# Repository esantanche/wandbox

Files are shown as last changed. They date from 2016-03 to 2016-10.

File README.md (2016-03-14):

Wandbox, Raspberry Pi 3 Laptop 
===================

This is a project for a laptop based on Raspberry Pi 3.
The components are contained in a plywood box.
The monitor will be mounted on top of the box.

Where to begin
--------------
Schematics_Components.odg shows how the laptop's components are placed and how power flows from the external power 
supply to the battery charger, to the batteries, to the switch and, from there to all other components.

The documents whose name begins with "Components" describe single components, where I plan to buy them from and
give technical details.

The documents whose name begins with "Tools" describe tools I'll use for the project.

The documents whose name begins with "Detail" show solutions used to solve specific problems.

Disclaimer
====================
I'm not endorsing any product here. I'm just saying which products I'm using.
You may find better products or completely different solutions.
Do your own research.

Do your own research about fire risks or any other risk. Carefully study how to minimise these risks.
I don't assume any responsibility if your home blows up and you with it. ;-)

Take care when using tools like saws or cutters, they are dangerous!

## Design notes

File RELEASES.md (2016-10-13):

Releases history
===================

1.0
===================
Made 3D and 2D schemas of box
Had the box's parts laser-cut
Built the box
Tested everything again
Added heating sinks
Completed many documents

0.3
===================
Tested these components: 12V voltage regulator, 5V voltage regulator, power switch. See results in PhotoGallery
Performed many experiments with batteries. Results in PhotoGallery as well.
Tested short HDMI cable
Tested keyboard
Updated many documents 
Started to design the plywood box. See document 010_what_the_box_will_be_like.odt in PhotoGallery

0.2
===================
I got the monitor! The delivery has been incredibly faster than expected.
I made many changes.
I'm using a different switch to power on the laptop. See ComponentsPowerOnSwitch.odt.
I made some photos with explanations. See PhotoGallery folder.

0.1
===================
Initial release

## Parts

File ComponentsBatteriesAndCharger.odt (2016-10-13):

Components:

Batteries and charger

# Batteries

These are 4400 mAh batteries for a total voltage of 11.1V (3.7 x 3)

http://www.ebay.com/itm/SAMSUNG-Rechargeable-Li-ion-Battery-18650-22F-11-1V-4400MAH-3S2P-6pcs-cell-/220999843383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

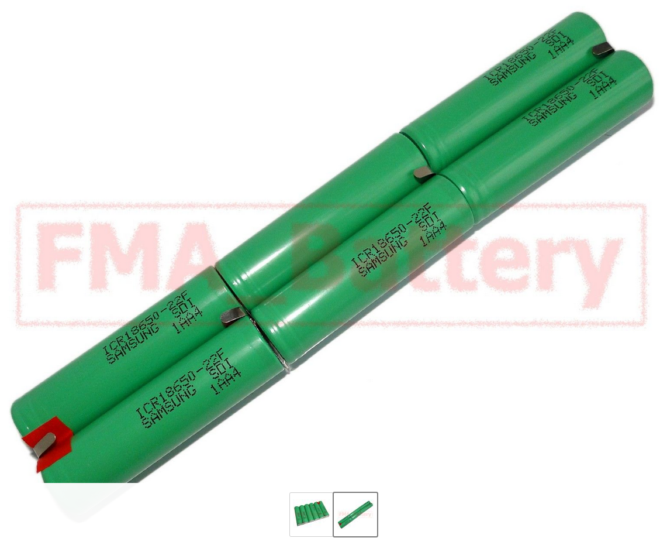
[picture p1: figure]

# Battery charger

It charges batteries and balances battery charge so that there is no risk that a battery ends up overcharged with the other batteries undercharged. It protects the batteries from overcharge, overcurrent and short circuit.

http://www.ebay.com/itm/Balance-BMS-Protected-Module-PCM-3S-4A-11-1V-Li-ion-Li-Po-Battery-3S4W007-/221791091395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

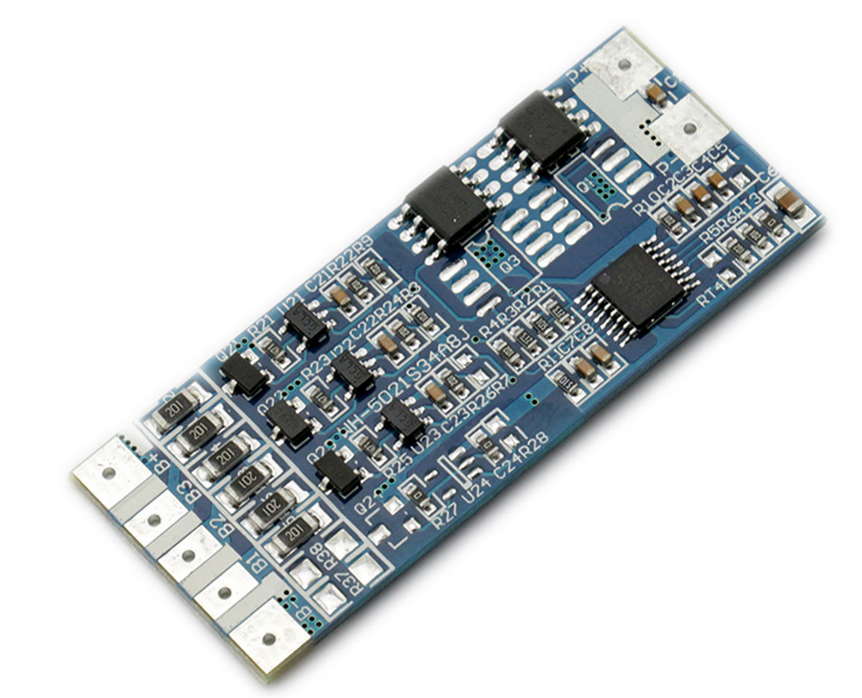
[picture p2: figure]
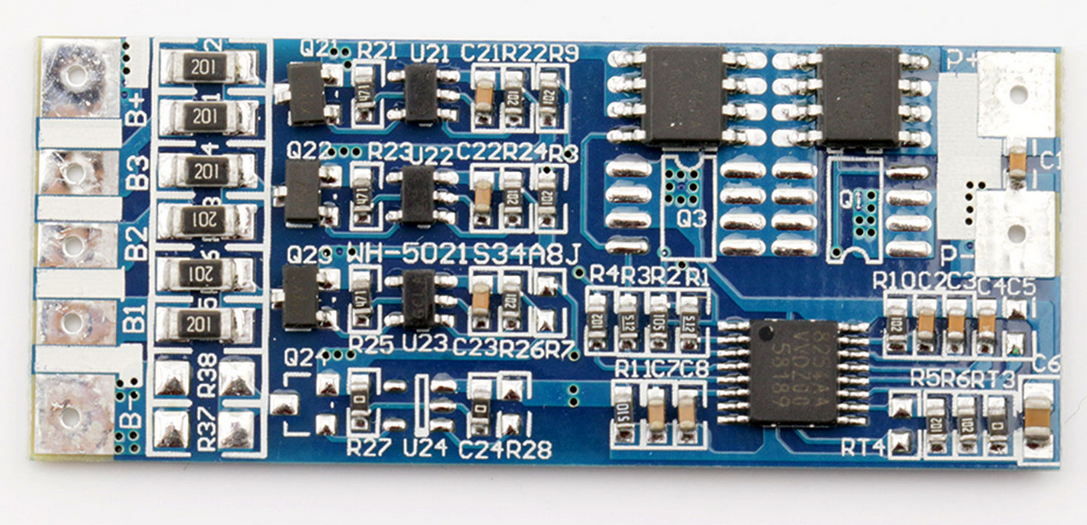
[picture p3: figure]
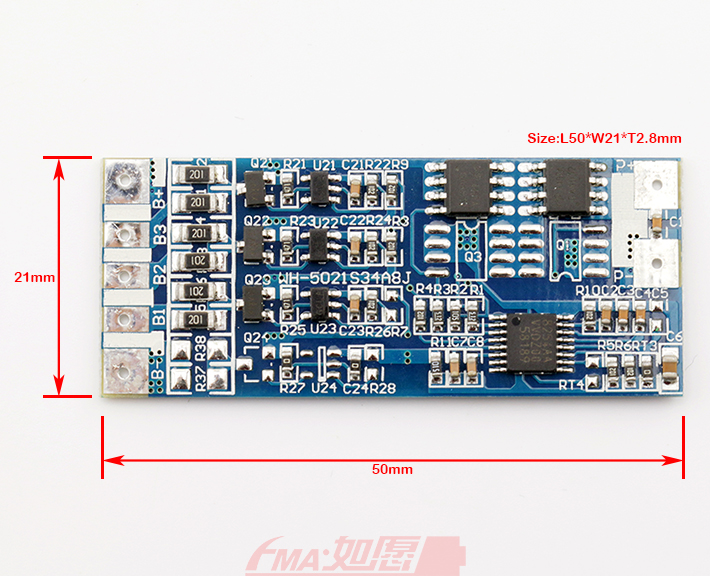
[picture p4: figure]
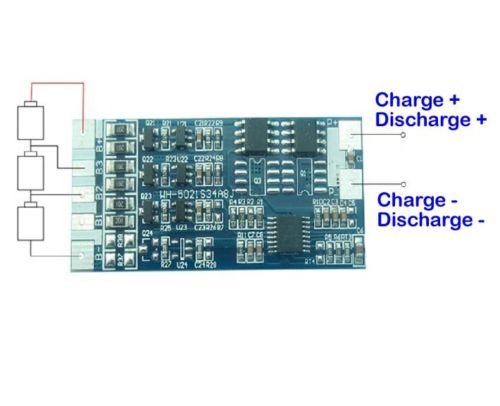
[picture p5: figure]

No | Test Item | | Criterion
1 | Voltage | Charging voltage | DC:13.5-15V CC/CV
| | Balance voltage for single cell | 4.2V
2 | Current | Balance current for single cell | 42mA
| | Current consumption | ≤15μA
| | Maximal continuous charging current | N/A
| | Maximal continuous Discharging current | 4.5A
3 | Over charge Protection | Over charge detection voltage | 4.350±0.025V
| | Over charge detection delay time | 1S
| | Over charge release voltage | 4.15±0.05V
4 | Over discharge protection | Over discharge detection voltage | 2.7±0.08V
| | Over discharge detection delay time | 100mS
| | Over discharge release voltage | 3.0±0.1V
5 | Over current protection | Over current detection voltage | 200±25mV
| | Over current detection current | 17±3A
| | Detection delay time | 10ms
| | Release condition | Cut load
6 | Short Circuit protection | Detection condition | Exterior short circuit
| | Detection delay time | ≤600us
| | Release condition | Cut load
7 | Resistance | Protection circuitry（MOSFET） | ≤15mΩ
8 | Temperature | Operating Temperature Range | -40～+85℃
| | Storage Temperature Range | -40～+125℃

# Min and max voltage of batteries

When fully charged these batteries have a 4.2V voltage. Which means 12.6V total voltage. The monitor should be able to tolerate this voltage even with no voltage regulator.

When discharging batteries go as low as 3V. This is a real minimum. So we have at least 9V in total.

https://learn.adafruit.com/li-ion-and-lipoly-batteries/voltages

# Additional charging and protection circuitry

Maybe I have to buy another one

http://www.ebay.co.uk/itm/111526325783?_trksid=p2055119.m1438.l2649&ssPageName=STRK%3AMEBIDX%3AIT

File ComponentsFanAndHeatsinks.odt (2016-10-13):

Fan and heatsinks

# Heatsinks

I got these heatsinks:

https://www.modmypi.com/raspberry-pi/accessories/heat-sinks-and-cooling/raspberry-pi-heat-sink-kit-red/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

As shown in the document 014_Overtemperature_problem.odt heatsinks don't lower cpu's temperature so much. But anyway, they are a start.

# Fans

I could get a fan like this one:

http://www.ebay.co.uk/itm/400895288849

Or maybe this one:

http://www.dx.com/p/active-cooling-mini-fan-for-raspberry-pi-3-model-b-2b-b-black-430935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

Or this one:

http://uk.rs-online.com/web/p/axial-fans/7588194/

For now I'll leave it as it is because, anyway, I'm not going to use the laptop for intensive tasks. The temperature should get very high.

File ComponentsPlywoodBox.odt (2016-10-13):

Components:

Plywood box

# 6.4 mm and 3.2 mm plywood

Initially I wanted to use 6.4 mm and 3.2 mm plywood.

This is the product I wanted to use:

http://modelshop.co.uk/Shop/Raw-Materials/Wood-Sheet/Item/Plywood-304-304mm/ITM3996

I got a single 6.4 mm sheet just to mount components on and test them.

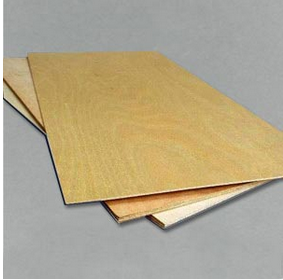
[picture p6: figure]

The problem is that this plywood is not suitable for laser cutting.

# Laser quality plywood

So I used laser quality plywood.

This is the product:

http://modelshop.co.uk/Shop/Raw-Materials/Wood-Sheet/Plywood/Item/Plywood-800-450mm/ITM4013

# Drawings

Drawing filename | Type of file | Description
2d-drawing-to-cut-box-parts-4-mm-plywood-sheet.dxf | LibreCAD | This is the drawing sent to Modelshop.co.uk for them to cut the parts I needed to build the box
2d-drawing-to-cut-box-parts-4-mm-plywood-sheet (red lines).dxf | LibreCAD | This is the same with red lines for another laser cut service I didn't actually use
wandbox-wings3d.wings | Wings3D | 3D model of the box with 6.4 mm and 3.2 mm plywood. I didn't build this box eventually
wandbox-wings3d-4mm-plywood.wings | Wings3D | 3D model of the box I actually built

# Other laser cutting services

http://www.cutlasercut.com

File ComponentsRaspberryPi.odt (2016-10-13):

Components:

Raspberry Pi

I got a Raspberry Pi 3:

https://www.newit.co.uk/shop/all-raspberry-pi/raspberry_pi_3/raspberry_pi3

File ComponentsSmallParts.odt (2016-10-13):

Components:

Small parts

# Screws

I need these sizes:

- length 5 mm (this are used for components that are directly screwed to plywood)
- length 8 mm (to mount the raspberry pi; these have to be longer because the raspberry pi needs space underneath, it can't be mounted directly to plywood)

I got these screws from a local modelling shop.

I got 9.5 mm and 6.4 mm ones.

I got as well 8 mm screws needed for 4mm plywood.

I got them here: http://www.ebay.co.uk/itm/272176439778?_trksid=p2057872.m2749.l2649&ssPageName=STRK%3AMEBIDX%3AIT

# DC Power Plug

http://www.hobbytronics.co.uk/cables-connectors/misc-connectors/dc-power-plug

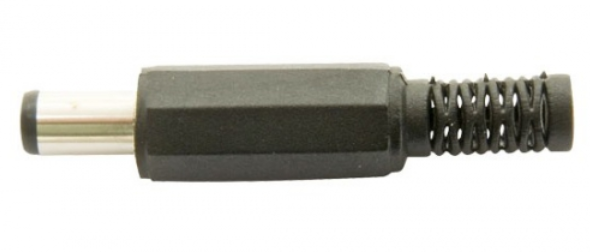
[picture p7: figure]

This is to power the monitor control board.

# Spacers

I'm going to use these spacers to make space between Raspberry Pi and the plywood box. I'll use them for all other boards.

http://www.hobbytronics.co.uk/hardware/spacers-washers/nylon-round-spacer-4mm

# Washers

I used washers for the monitor control board.

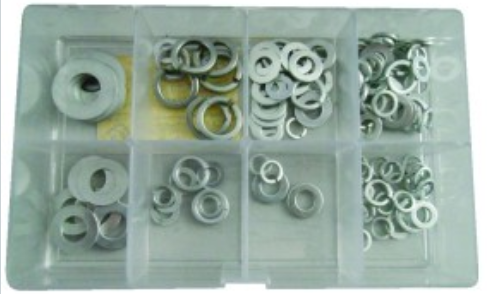
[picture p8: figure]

These are metallic washers, but for the monitor control board it's fine.

I had to use them because the monitor control board has quite large mounting holes and my screws are small.

I got these metallic washers from Maplin.

I got more washers, smaller ones, here: http://www.modelfixings.co.uk/washers.htm#Flat washers

These are M2 washers I needed because my screws are small and the washers I already had were too big.

Other examples

- http://www.hobbytronics.co.uk/hardware/spacers-washers/nylon-washer-m25
- http://uk.rs-online.com/web/p/products/0528154/
- http://www.ebay.co.uk/itm/M3-M4-M5-M6-M8-M10-M20-Nylon-Washer-Plastic-Washer-Nylon-Insulation-Soft-Gasket-/171983814762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 (http://www.ebay.co.uk/itm/M3-M4-M5-M6-M8-M10-M20-Nylon-Washer-Plastic-Washer-Nylon-Insulation-Soft-Gasket-/171983814762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)

# Cable

It has to be 0.8 or 1 mm of diameter.

I got a 0.6mm one that should be OK anyway because it's rated 4A. I got it from Maplin.

It's a rigid cable that has a single core.

# Jumpers

Jumpers 1x2 to power Raspberry Pi via GPIO and to use to connect boards.

http://www.hobbytronics.co.uk/crimp-conn-housing-2


Pins to be inserted in the jumpers above:

http://www.hobbytronics.co.uk/crimp-conn-pins


Other products:

- http://uk.rs-online.com/web/p/products/7916450/#
- http://www.maplin.co.uk/p/jumper-wires-raspberry-pi-40-way-ribbon-male-female-tear-off-strips-n75de
- http://www.hobbytronics.co.uk/cables-connectors/crimp-connectors/crimp-conn-housing-22
- http://www.hobbytronics.co.uk/cables-connectors/jumper-wires-mf-6in

Other ideas:

How to make your own jumpers: http://www.basicxandrobotics.com/tutorials/jumpers/

How to make custom connectors: https://www.youtube.com/watch?v=M84VcMeAzzw

# Cable tie bases

Now I'm not using these cable ties.

Maplin has them.

Useful to tie small cables.

This is just an example to show what I'm talking about:

http://www.ebay.co.uk/itm/SELF-ADHESIVE-CABLE-TIE-BASE-MOUNTS-STICKY-BACKED-BLACK-WHITE-19mm-25mm-28mm-/181011054666

# Crimp terminals

I used crimps only to connect the batteries. To distribute power I used terminals.

I used crimps like these:


I got some other crimp terminals with the crimper, but I haven't used them.

Eventually I used a lot of terminals to distribute power.


Terminals

# Fasteners

I'm not going to use these.

These cable ties are used to fasten the batteries:

http://www.cabletiesonline.co.uk/cable-ties-screw-mount/screw-mount-cable-ties-110-x-2-5mm/prod_961.html

# Crocodile clips

I got a couple of crocodile clips from my old stuff.

http://www.hobbytronics.co.uk/crocodile-clips?keyword=clip

Useful information:

How to attach an alligator clip to a wire

https://www.youtube.com/watch?v=DrEzG1gwYOg

# Plastic profiles

I used plastic profiles for the box. They allow me to place screws not too near the borders. If I put a screw near a border, it damages the wood.


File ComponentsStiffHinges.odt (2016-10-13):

Components:

Stiff hinges

These hinges make it possible to adjust the incline of the monitor.

They are stiff, which means that they stay put at the angle you give them.

This is the link to the product: http://uk.rs-online.com/web/p/hinges/7729638/


Hinges at work!


These hinges are adjustable. If they don't stay put at the angle you give them, you can tight the screws and they get more stiff.

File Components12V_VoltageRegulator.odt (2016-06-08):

Components:

12V Voltage regulator

This voltage regulator is for the monitor.

I'm using this one:

http://www.hobbytronics.co.uk/s18v20f12-12v-regulator


### How I used it

I just soldered the blue terminals you see above to the pins GND, VIN and VOUT. VIN has to be connected to the positive pole of the batteries charger or of the PSU. VOUT goes to the monitor. The GND pin on the input side has to be connected to the negative pole of the batteries charger or of the PSU. The GND pin on the output side goes to the monitor. No need to use the ENABLE pin.

### 12V Step-Up/Step-Down Voltage Regulator S18V20F12

This powerful step-up/step-down regulator efficiently produces a fixed 12 V output from input voltages between 3 V and 30 V while allowing a typical output current of up to 2 A when the input voltage is close to the output voltage and offering typical efficiencies of 80% to 90%. Its ability to convert both higher and lower input voltages makes it useful for applications where the power supply voltage can vary greatly, as with batteries that start above but discharge below the regulated voltage.

The flexibility in input voltage offered by these regulators is especially well-suited for battery-powered applications in which the battery voltage begins above the desired output voltage and drops below the target as the battery discharges.

The no-load quiescent will typically be between 1mA and 5mA for all possible combinations of input and output voltages (e.g. the quiescent current is approximately 4mA with 3V in, 1.5mA with 12V in, and 1mA with 30V in). The ENABLE pin can be used to put the board in a low-power state that reduces the quiescent current to between 10 and 20µA per volt on VIN (e.g. approximately 30µA with 3V in and 500µA with 30V in).

This regulator has built-in reverse-voltage protection, over-current protection, thermal shutdown (which typically activates at 165°C), and an under-voltage lockout that causes the regulator to turn off when the input voltage is below 2.5 V (typical).

Features

- Input voltage: 2.9V to 32V (32 V is the absolute maximum operating voltage; the recommended maximum operating voltage is 30 V, which is the limit of the reverse voltage protection.)
- Fixed 12V output with 4% accuracy
- Typical maximum continuous output current: 2A (when input voltage is close to the output voltage; the Typical Efficiency and Output Current section below shows how the achievable continuous output current depends on input and output voltages)
- Integrated reverse-voltage protection (up to 30V), over-current protection, over-temperature shutoff, and under-voltage lockout
- Typical efficiency of 80% to 90%, depending on input voltage, output voltage, and load
- Four mounting holes for #2 or M2 screws.
- Compact size: 1.7″ × 0.825″ × 0.38″ (43 × 21 × 10 mm)
- Smaller holes for 0.1″ header pins and larger holes for terminal blocks offer several options for connecting to the board.

Connections

This step-up/step-down regulator has four connections: input voltage (VIN), ground (GND), and output voltage (VOUT), and ENABLE.

The input voltage, VIN, should be between 2.9 V and 32 V. Lower input voltages can cause the regulator to shut down or behave erratically; higher input voltages can destroy the regulator, so you should ensure that noise on the input is not excessive. 32 V should be treated as the absolute maximum input voltage. Our recommended maximum operating voltage is 30 V, which is the limit of the reverse voltage protection.

The regulator is enabled by default: a 100 kΩ pull-up resistor on the board connects the ENABLE pin to reverse-protected VIN. The ENABLE pin can be driven low (under 0.7 V) to put the board into a low-power state. The quiescent current draw in this sleep mode is dominated by the current in the pull-up resistor from ENABLE to VIN and by the reverse-voltage protection circuit, which will draw between 10 µA and 20 µA per volt on VIN when ENABLE is held low (e.g. approximately 30 µA with 3 V in and 500 µA with 30 V in). If you do not need this feature, you should leave the ENABLE pin disconnected. Note that the SEPIC topology has an inherent capacitor from input to output; therefore, the output is not completely disconnected from the input even when the regulator is shut down.

Output Current

The maximum achievable output current of the board varies with the input voltage but also depends on other factors, including the ambient temperature, air flow, and heat sinking. The graphs below show output currents at which this voltage regulator’s over-temperature protection typically kicks in after a few seconds. These currents represent the limit of the regulator’s capability and cannot be sustained for long periods, so the continuous currents that the regulator can provide are typically several hundred milliamps lower.

## Other ideas

- https://www.coolcomponents.co.uk/adjustable-4-12v-step-up-step-down-voltage-regulator-s18v20alv.html

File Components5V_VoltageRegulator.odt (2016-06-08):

Components:

5V Voltage regulator

This voltage regulator is to power the Raspberry Pi.

This is the 5V voltage regulator I got:

http://www.hobbytronics.co.uk/electronic-components/voltage-regulators/voltage-regulator-5v/d24v22f5-5v-step-down-regulator


### How I used it

I needed just to connect GND to the negative pole of the batteries charger. The latter, when it's not under charge, allows the batteries power to flow through it to power anything you connect to it.

The pin VIN has to be connected to the batteries charger as well.

The pin VOUT goes to power the Raspberry Pi. The latter will take GND from the battery charger.

There is no need to use the pins PG and EN.

### 5V 2.5A Step-Down Voltage Regulator D24V22F5

This small synchronous switching step-down (or buck) regulator takes an input voltage of up to 36 V and efficiently reduces it to 5 V. The board measures only 0.7″ × 0.7″ yet delivers a typical continuous output current of up to 2.5 A and features reverse voltage protection. Typical efficiencies of 85% to 95% make this regulator well suited for powering moderate loads like sensors or small motors. An optional shutdown pin enables a low-power state with a current draw of around 20 μA to 350 μA, depending on the input voltage, and a power-good output indicates when the regulator cannot adequately maintain the output voltage.

These regulators have a typical quiescent (no load) current draw of around 1 mA, and an enable pin can be used to put the boards in a low-power state that reduces the quiescent current to approximately 5 µA to 10 µA per volt on VIN.

The modules have built-in reverse-voltage protection, short-circuit protection, a thermal shutdown feature that helps prevent damage from overheating, and a soft-start feature that reduces inrush current.

Features

- Input voltage: 6 V to 38 V (see below for more details on the regulator’s dropout voltage, which affects the low end of the operating range)
- Fixed 5 V output (with 4% accuracy)
- Typical maximum continuous output current: > 2.5 A
- Integrated reverse-voltage protection, over-current protection, over-temperature shutoff, soft-start, and under-voltage lockout
- Typical efficiency of 85% to 95%, depending on input voltage and load; the switching frequency automatically changes at light loads to maintain high efficiencies
- 1 mA typical no-load quiescent current; this can be reduced to approximately 5 µA to 10 µA per volt on VIN by disabling the board
- “Power good” output indicates when the regulator cannot adequately maintain the output voltage
- Compact size: 0.7″ × 0.7″ × 0.31″ (17.8 mm × 17.8 mm × 8 mm)
- Two 0.086″ mounting holes for #2 or M2 screws

These buck regulators have five main connection points for five different electrical nodes: power good (PG), enable (EN), input voltage (VIN), ground (GND), and output voltage (VOUT). The board also features a second ground connection point off the main row of connections that might be convenient for applications where you are soldering wires directly to the board rather than using it in a breadboard.

The input voltage, VIN, powers the regulator and can be supplied with voltages up to 38 V. The effective lower limit of VIN is VOUT plus the regulator’s dropout voltage, which varies approximately linearly with the load (see below for a graph of dropout voltages as a function of the load).

The regulator is enabled by default: a 270 kΩ pull-up resistor on the board connects the EN pin to reverse-protected VIN. The EN pin can be driven low (under 1 V) to put the board into a low-power state. The quiescent current draw in this sleep mode is dominated by the current in the pull-up resistor from EN to VIN and by the reverse-voltage protection circuit, which altogether will draw between 5 µA and 10 µA per volt on VIN when EN is held low. If you do not need this feature, you should leave the EN pin disconnected.

The “power good” indicator, PG, is an open-drain output that goes low when the regulator’s output voltage falls below around 85% of the nominal voltage and becomes high-impedance when the output voltage rises above around 90%. An external pull-up resistor is required to use this pin.

## Other ideas

- http://www.dx.com/p/hobbywing-5v-6v-3a-switch-mode-ultimate-bec-ubec-15149#.VuCzLeinxJ8
- http://www.dx.com/p/8s-5a-switch-mode-ultimate-bec-ubec-45214#.VuFjIjp6elN
- http://uk.rs-online.com/web/p/products/0633026/

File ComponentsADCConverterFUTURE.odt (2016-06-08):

FIXME I'll add this in the future

(https://shop.pimoroni.com/products/adafruit-ads1115-16-bit-adc-4-channel-with-programmable-gain-amplifier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)

https://shop.pimoroni.com/products/adafruit-ads1115-16-bit-adc-4-channel-with-programmable-gain-amplifier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

FIXME future addition

ADC converter to measure batteries voltage

You have to enable I2C interface in raspberry pi configuration

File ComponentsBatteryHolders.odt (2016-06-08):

Components:

Battery holders

I didn't use battery holders.


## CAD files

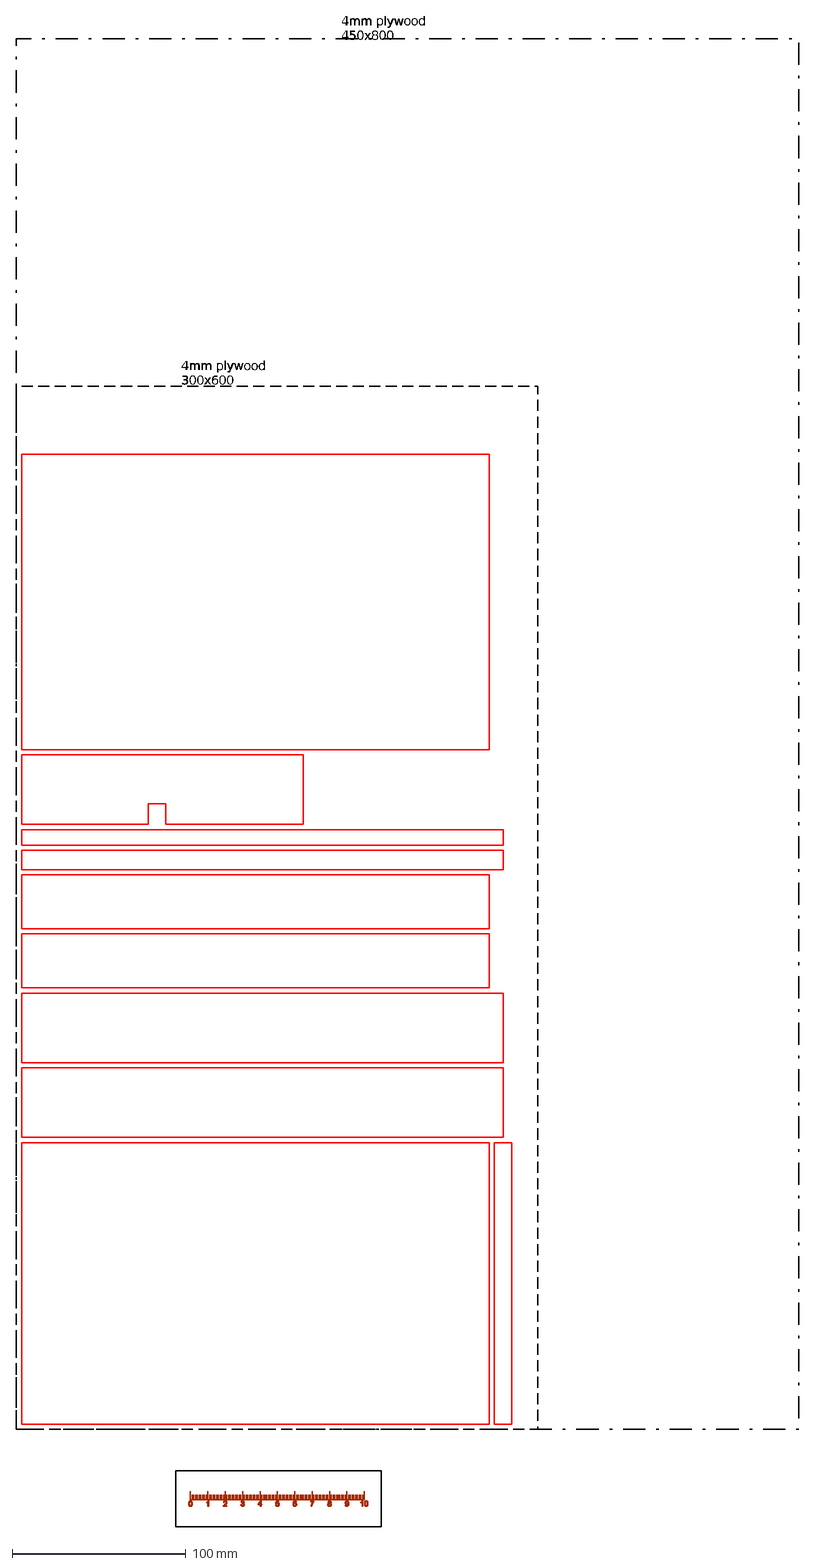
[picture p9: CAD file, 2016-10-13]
2d-drawing-to-cut-box-parts-4-mm-plywood-sheet (red lines).dxf
4mm plywood 300x600
4mm plywood 450x800

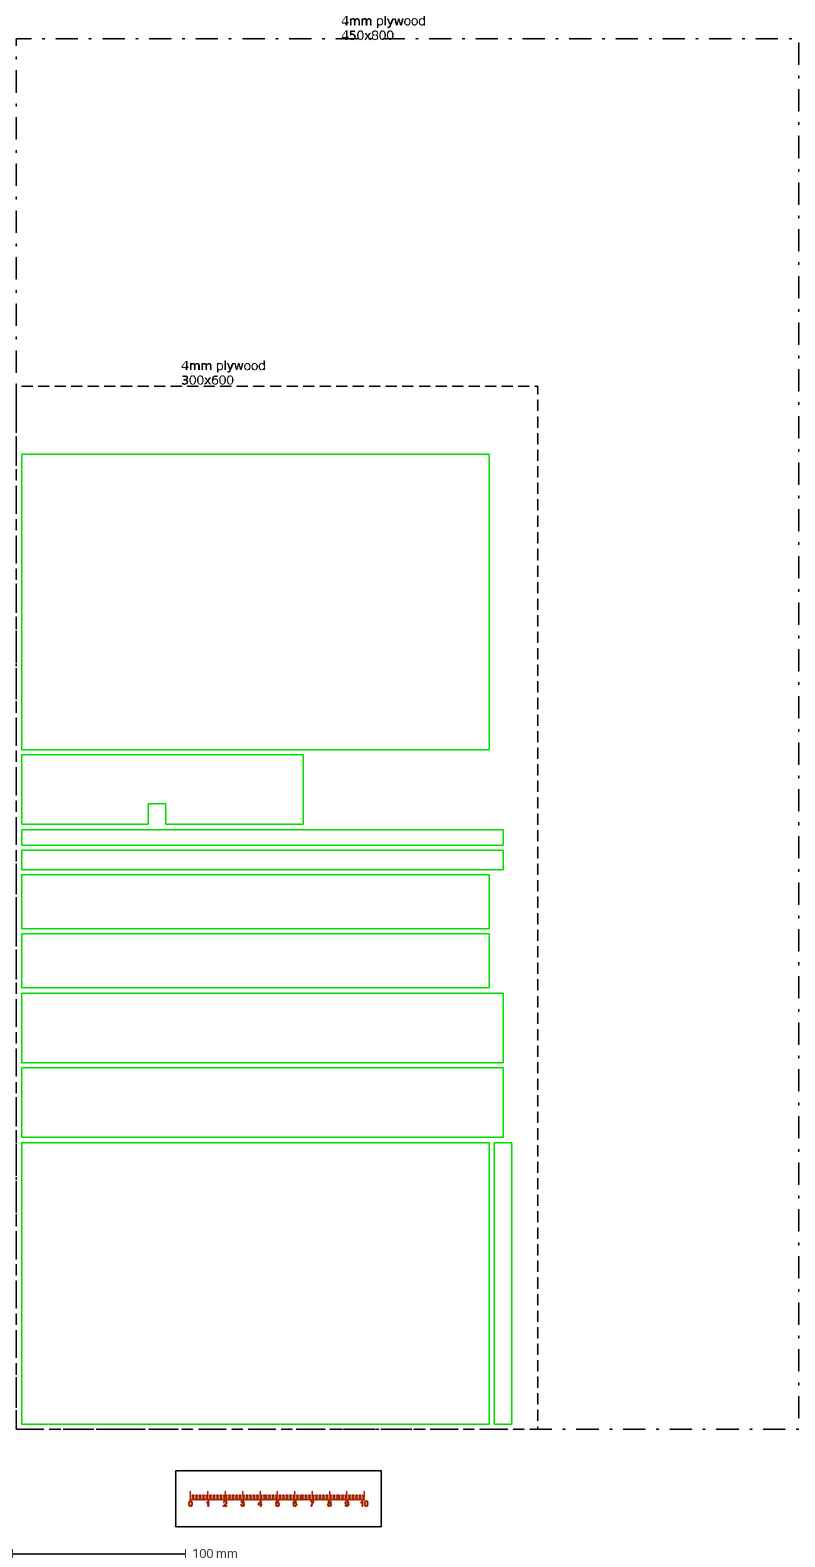
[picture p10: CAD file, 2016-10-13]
2d-drawing-to-cut-box-parts-4-mm-plywood-sheet.dxf
4mm plywood 300x600
4mm plywood 450x800

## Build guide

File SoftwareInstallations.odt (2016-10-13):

Wandbox, software installations

# Installation of NOOBS

Followed standard procedure from https://www.raspberrypi.org/help/noobs-setup/

Just make sure that the SD card is formatted FAT32 and not extended FAT.

# Connect to wifi

Click on the network icon on the right of the top panel.

You get a list of wifi networks. You may have to wait a little for the scan to complete.

Select your wifi network.

Give your password.

# Update and upgrade

To update Raspbian to latest version, give these commands:

sudo apt-get update

sudo apt-get dist-upgrade

reboot.

# Set locale and keyboard

Go to Menu→Preferences→Raspberry Pi configuration

Go to localisation tab

Set your locale, timezone and keyboard

# Firefox

Go to Menu→Preferences→Add/Remove Software

Search for Firefox

Select “Mozilla Firefox web browser”

Click Apply

The password is raspberry if you didn't change it.

# Chromium

With this procedure you install Chromium:

wget -qO - http://bintray.com/user/downloadSubjectPublicKey?username=bintray | sudo apt-key add -
echo "deb http://dl.bintray.com/kusti8/chromium-rpi jessie main" | sudo tee -a /etc/apt/sources.list
sudo apt-get update
sudo apt-get install chromium-browser rpi-youtube -y

It works!

You find chromium in the menu and you can add it to the top panel.

# Flash plugin for chromium

This is not needed if you followed the procedure above to install chromium.

Following (with some changes) this procedure: https://www.raspberrypi.org/forums/viewtopic.php?t=99202

pi@raspberrypi:~/Desktop $ wget http: (http://de4.mirror.archlinuxarm.org/armv7h/alarm/chromium-pepper-flash-12.0.0.77-1-armv7h.pkg.tar.xz)// (http://de4.mirror.archlinuxarm.org/armv7h/alarm/chromium-pepper-flash-12.0.0.77-1-armv7h.pkg.tar.xz)de4.mirror.archlinuxarm.org (http://de4.mirror.archlinuxarm.org/armv7h/alarm/chromium-pepper-flash-12.0.0.77-1-armv7h.pkg.tar.xz)/ (http://de4.mirror.archlinuxarm.org/armv7h/alarm/chromium-pepper-flash-12.0.0.77-1-armv7h.pkg.tar.xz)armv7h (http://de4.mirror.archlinuxarm.org/armv7h/alarm/chromium-pepper-flash-12.0.0.77-1-armv7h.pkg.tar.xz)/ (http://de4.mirror.archlinuxarm.org/armv7h/alarm/chromium-pepper-flash-12.0.0.77-1-armv7h.pkg.tar.xz)alarm (http://de4.mirror.archlinuxarm.org/armv7h/alarm/chromium-pepper-flash-12.0.0.77-1-armv7h.pkg.tar.xz)/ (http://de4.mirror.archlinuxarm.org/armv7h/alarm/chromium-pepper-flash-12.0.0.77-1-armv7h.pkg.tar.xz)chromium-pepper-flash (http://de4.mirror.archlinuxarm.org/armv7h/alarm/chromium-pepper-flash-12.0.0.77-1-armv7h.pkg.tar.xz)-12.0.0.77-1 (http://de4.mirror.archlinuxarm.org/armv7h/alarm/chromium-pepper-flash-12.0.0.77-1-armv7h.pkg.tar.xz)-armv7h.pkg. (http://de4.mirror.archlinuxarm.org/armv7h/alarm/chromium-pepper-flash-12.0.0.77-1-armv7h.pkg.tar.xz)tar (http://de4.mirror.archlinuxarm.org/armv7h/alarm/chromium-pepper-flash-12.0.0.77-1-armv7h.pkg.tar.xz).xz (http://de4.mirror.archlinuxarm.org/armv7h/alarm/chromium-pepper-flash-12.0.0.77-1-armv7h.pkg.tar.xz)

pi@raspberrypi:~/Desktop $ tar xf chromium-pepper-flash-12.0.0.77-1-armv7h.pkg.tar.xz

pi@raspberrypi:~/Desktop $ cd usr/lib/PepperFlash/

pi@raspberrypi:~/Desktop/usr/lib/PepperFlash $ chmod +x *

pi@raspberrypi:~/Desktop/usr/lib/PepperFlash $ sudo cp * /usr/lib/chromium-browser/plugins/

pi@raspberrypi:~/Desktop/usr/lib/PepperFlash $ sudo nano /etc/chromium-browser/default

Changes to be done to file /etc/chromium-browser/default:

# Options to pass to chromium-browser

#CHROMIUM_FLAGS=""

CHROMIUM_FLAGS="--ppapi-flash-path=/usr/lib/chromium/plugins/libpepflashplayer.so --ppapi-flash-version=12.0.0.77 -password-store=detect -user-data-dir"

# Enabling alias ll.

This is to use the command ll which is a shortcut for ls -al. When you want to list files in a folder you get file details as well instead of only the names

cd

nano .bashrc

find line that begins with #alias ll and make it like this:

alias ll='ls -al'

# Better fonts

Install package ttf-mscorefonts-installer-3.6 by using standard add-software function (Menu→Preferences→Add/Remove Software)

pi's password is raspberry

Run this command:

sudo dpkg-reconfigure fontconfig-config

choose Autohinter

choose Automatic

choose No

reboot

# Pairing the Bluetooth Keyboard

I'm no longer using blue-tooth keyboards.

Useful thread:

https://www.raspberrypi.org/forums/viewtopic.php?f=29&t=87138&p=752712#p752712

These are experiments done with a blue-tooth keyboard.

Enter bluetooth control:

bluetoothctl

Enter these commands:

agent KeyboardOnly
default-agent
discoverable on
pairable on
remove 20:73:AB:00:64:44
[bluetooth]# pair 20:73:AB:00:64:44
(just type the same code on the keyboard without pushing the button and give return at the end)
[bluetooth]# connect 20:73:AB:00:64:44

These command made the keyboard work. It had 20:73:AB:00:64:44 as mac address

This is useful to initialise blue-tooth:

#!/bin/bash
bluetoothctl << EOF
power on
discoverable on
agent on
default-agent
pairable on
EOF

# Change pi's password

default pi's password: raspberry

Just use the menu: Menu→Preferences→Raspberry Pi Configuration->System

You can change password and hostname.

# Stress test

I did this stress test for Raspberry Pi's cpu to see how much it consumes.

pi@raspberrypi:~ $ sudo apt-get install stress

pi@raspberrypi:~ $ stress --cpu 8 --io 4 --vm 2 --vm-bytes 128M --timeout 30s

# Monitor on off script

I want to switch the monitor off when I'm not using the laptop.

I'll do this with a script.

Begin with running these commands:

pi@raspberrypi:~ $ mkdir Scripts

pi@raspberrypi:~ $ cd Scripts/

pi@raspberrypi:~/Scripts $ nano monitor-on-off.sh

pi@raspberrypi:~/Scripts $ chmod +x monitor-on-off.sh

When running nano monitor-on-off.sh, copy and paste the script you will find in the following.

Add these two lines to the file /home/pi/.bashrc:

PATH=$PATH:/home/pi/Scripts

export PATH

They make it possible to run the script monitor-on-off.sh from any folder.

Test the script with this command:

monitor-on-off.sh off; sleep 20; monitor-on-off.sh on

The monitor should go off and on again.

Then you can associate the script with a key by editing this file:

/home/pi/.config/openbox/lxde-pi-rc.xml

This is the section to add before the closing </keyboard> tag:

<keybind key="F9">

<action name="Execute">

<command>/home/pi/Scripts/monitor-on-off.sh</command>

</action>

</keybind>

When you push F9 (with Logitech K400 keyboard remember to use the FN key as well), the monitor goes off and when you push it again it goes on again.

This is the content of the script monitor-on-off.sh:

#!/bin/bash

exec > >(tee -a "$HOME/Logs/monitor-on-off.log") 2>&1

echo `date +%H:%M:%S` About to check if monitor is on or off

MONITOR_IS_OFF=`tvservice -s | grep off | wc -l`

echo `date +%H:%M:%S` MONITOR_IS_OFF=$MONITOR_IS_OFF

if [ $MONITOR_IS_OFF -eq 1 ]; then

tvservice -p

fbset -depth 8

fbset -depth 16

xrefresh

echo 'Switched Screen ON!'

else

# This is needed otherwise you can't press F9 to switch monitor back on

xscreensaver-command -exit

tvservice -p

tvservice -o

echo 'Switched Screen OFF!'

fi

Additional notes:

The command tvservice -s gives this output when the monitor is off:

state 0x120002 [TV is off]

# How to install screen saver

pi@wandbox:/etc/X11/Xsession.d $ sudo apt-get update

pi@wandbox:/etc/X11/Xsession.d $ sudo apt-get install xscreensaver

Go to menu->preferences->screensaver

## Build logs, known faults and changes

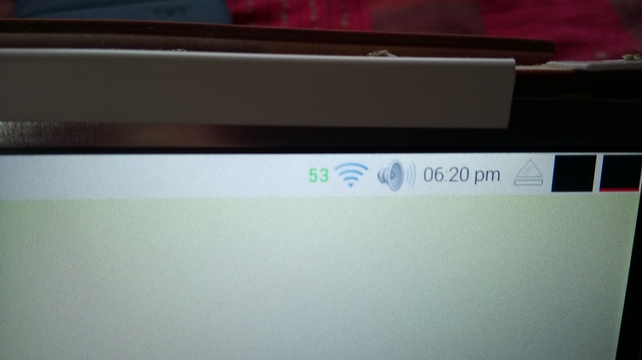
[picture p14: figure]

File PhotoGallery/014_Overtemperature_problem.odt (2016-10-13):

Raspberry's CPU was getting hot. When playing Youtube videos with Chromium browser, the cpu reaches temperatures as high as 80-85 °C.

I added a heat-sink, but cpu's temperature still is high.

Anyway, I'm not going to use this laptop so much for videos and, if I play videos, I'll use Firefox or “Web” (the browser you find pre-installed), which consume much less cpu.

# Over-Temperature Warning Icon

In this article you can see the icon that warns that cpu temperature is too high.

https://retroresolution.com/2016/03/24/overclocking-the-raspberry-pi-3-pragmatism-and-optimising-for-single-vs-multicore-performance/

I get this icon displayed when I play videos on Chromium.

# Heat-sinks don't make much difference

It's shown on this video: https://www.youtube.com/watch?v=e6okZKRwnTQ

You need a fan. A fan does make a difference: https://www.youtube.com/watch?v=5Ud-grj4Zl0

I may add a fan later.

# Adding the heat-sinks

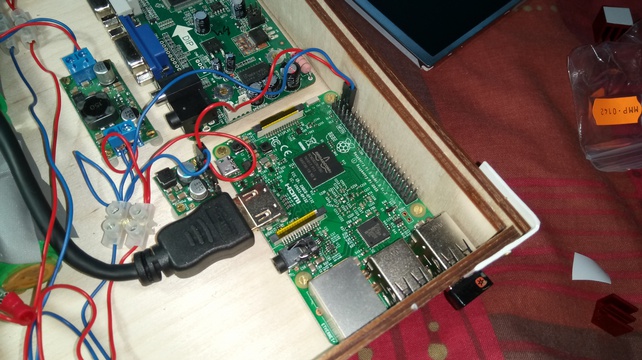
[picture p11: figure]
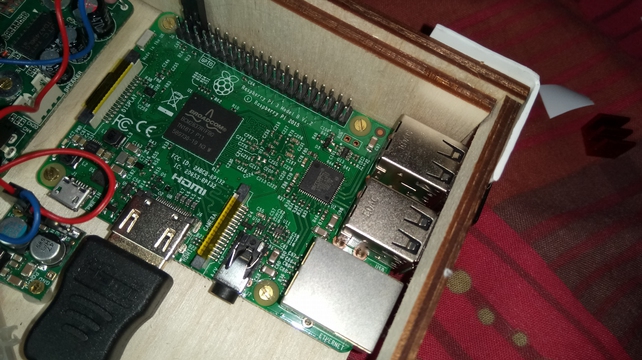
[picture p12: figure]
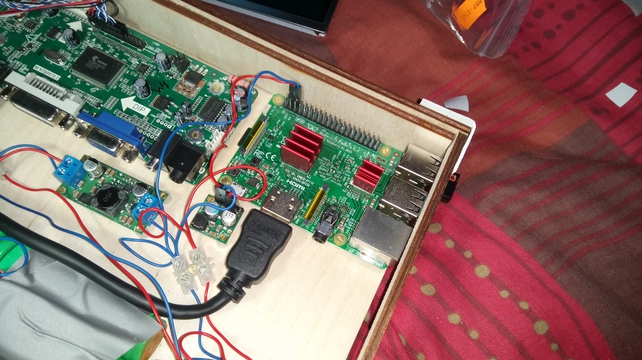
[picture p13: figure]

You can see here the panel applet that shows cpu temperature, 53 °C, which, to be Raspberry's cpu, it's very low.
